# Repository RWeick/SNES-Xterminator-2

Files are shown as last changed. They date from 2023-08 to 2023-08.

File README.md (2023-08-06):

# SNES-Xterminator-2
The Kicad files, rom dump, and GAL JEDEC for the SNES Xterminator 2 cheat device. I have redone the trace layout and added additional pads for SMD components.  
Standard jumper configuration: Pads 2, 4, 6, 8, 10, and 12 are shorted.  

Preliminary analysis suggests the following operation of the GAL, multiplexer, and NAND gates:  

/O19 = A 0xFFE8 and BA 0x0, 0x2, 0x4, 0x6

/SRAM.CS = A 0x2C00 to 0x2FFF and BA 0x0 to 0x1F, which aligns with the fact that the SRAM has 32,768 words.

When Famicom cart is inserted, Famicom CICs 1 and 2 are connected to the system.
When Famicom cart is not inserted, SNES cart CICs 1 and 2 are connected to the system.

The operation of the 18CV8PC is unknown at this time, but I will be analyzing it in operation for reverse engineering.

Main Board PCB Thickness: 1.2 mm  
Cartridge Connector Board PCB Thickness: 1.6 mm  

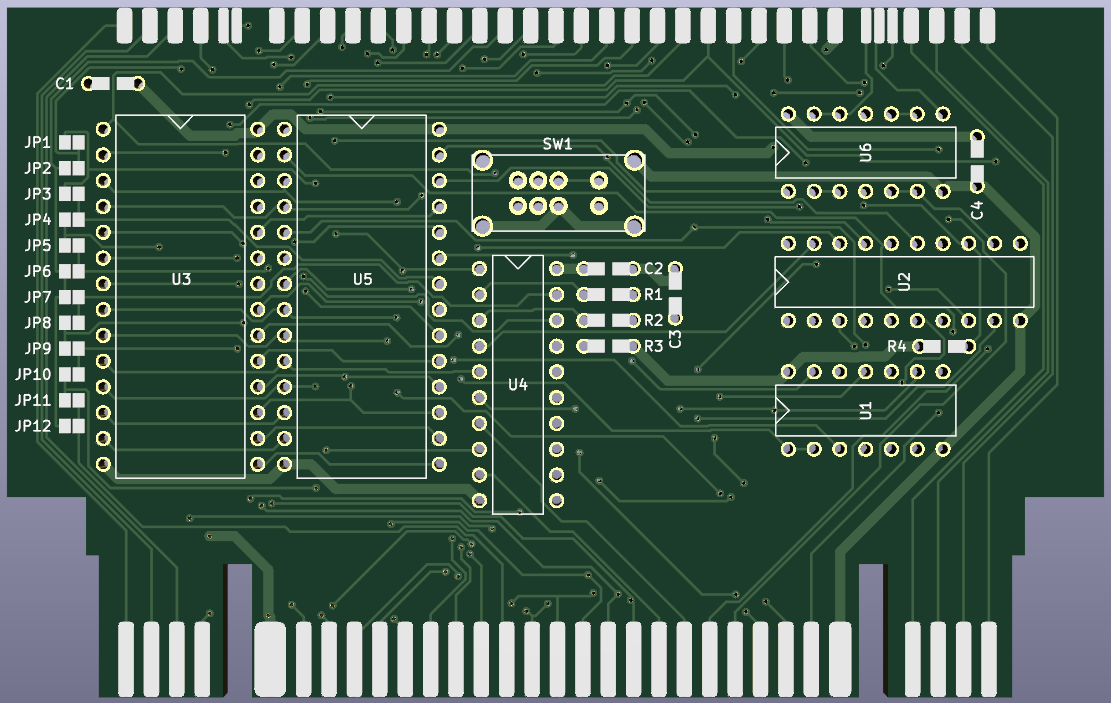
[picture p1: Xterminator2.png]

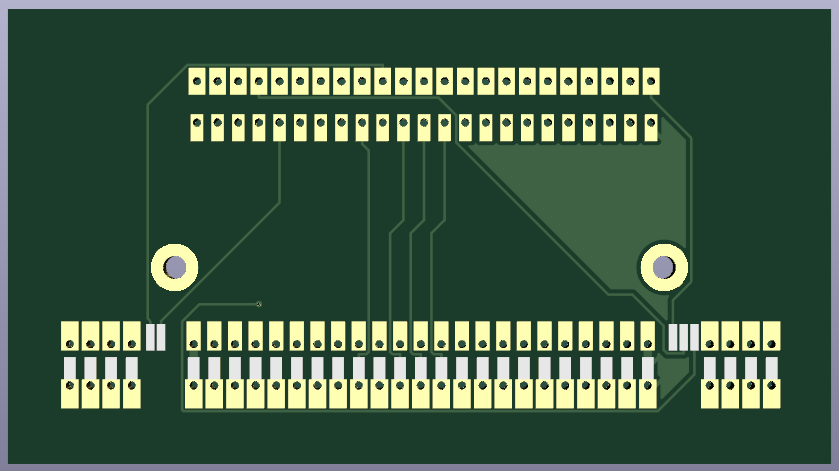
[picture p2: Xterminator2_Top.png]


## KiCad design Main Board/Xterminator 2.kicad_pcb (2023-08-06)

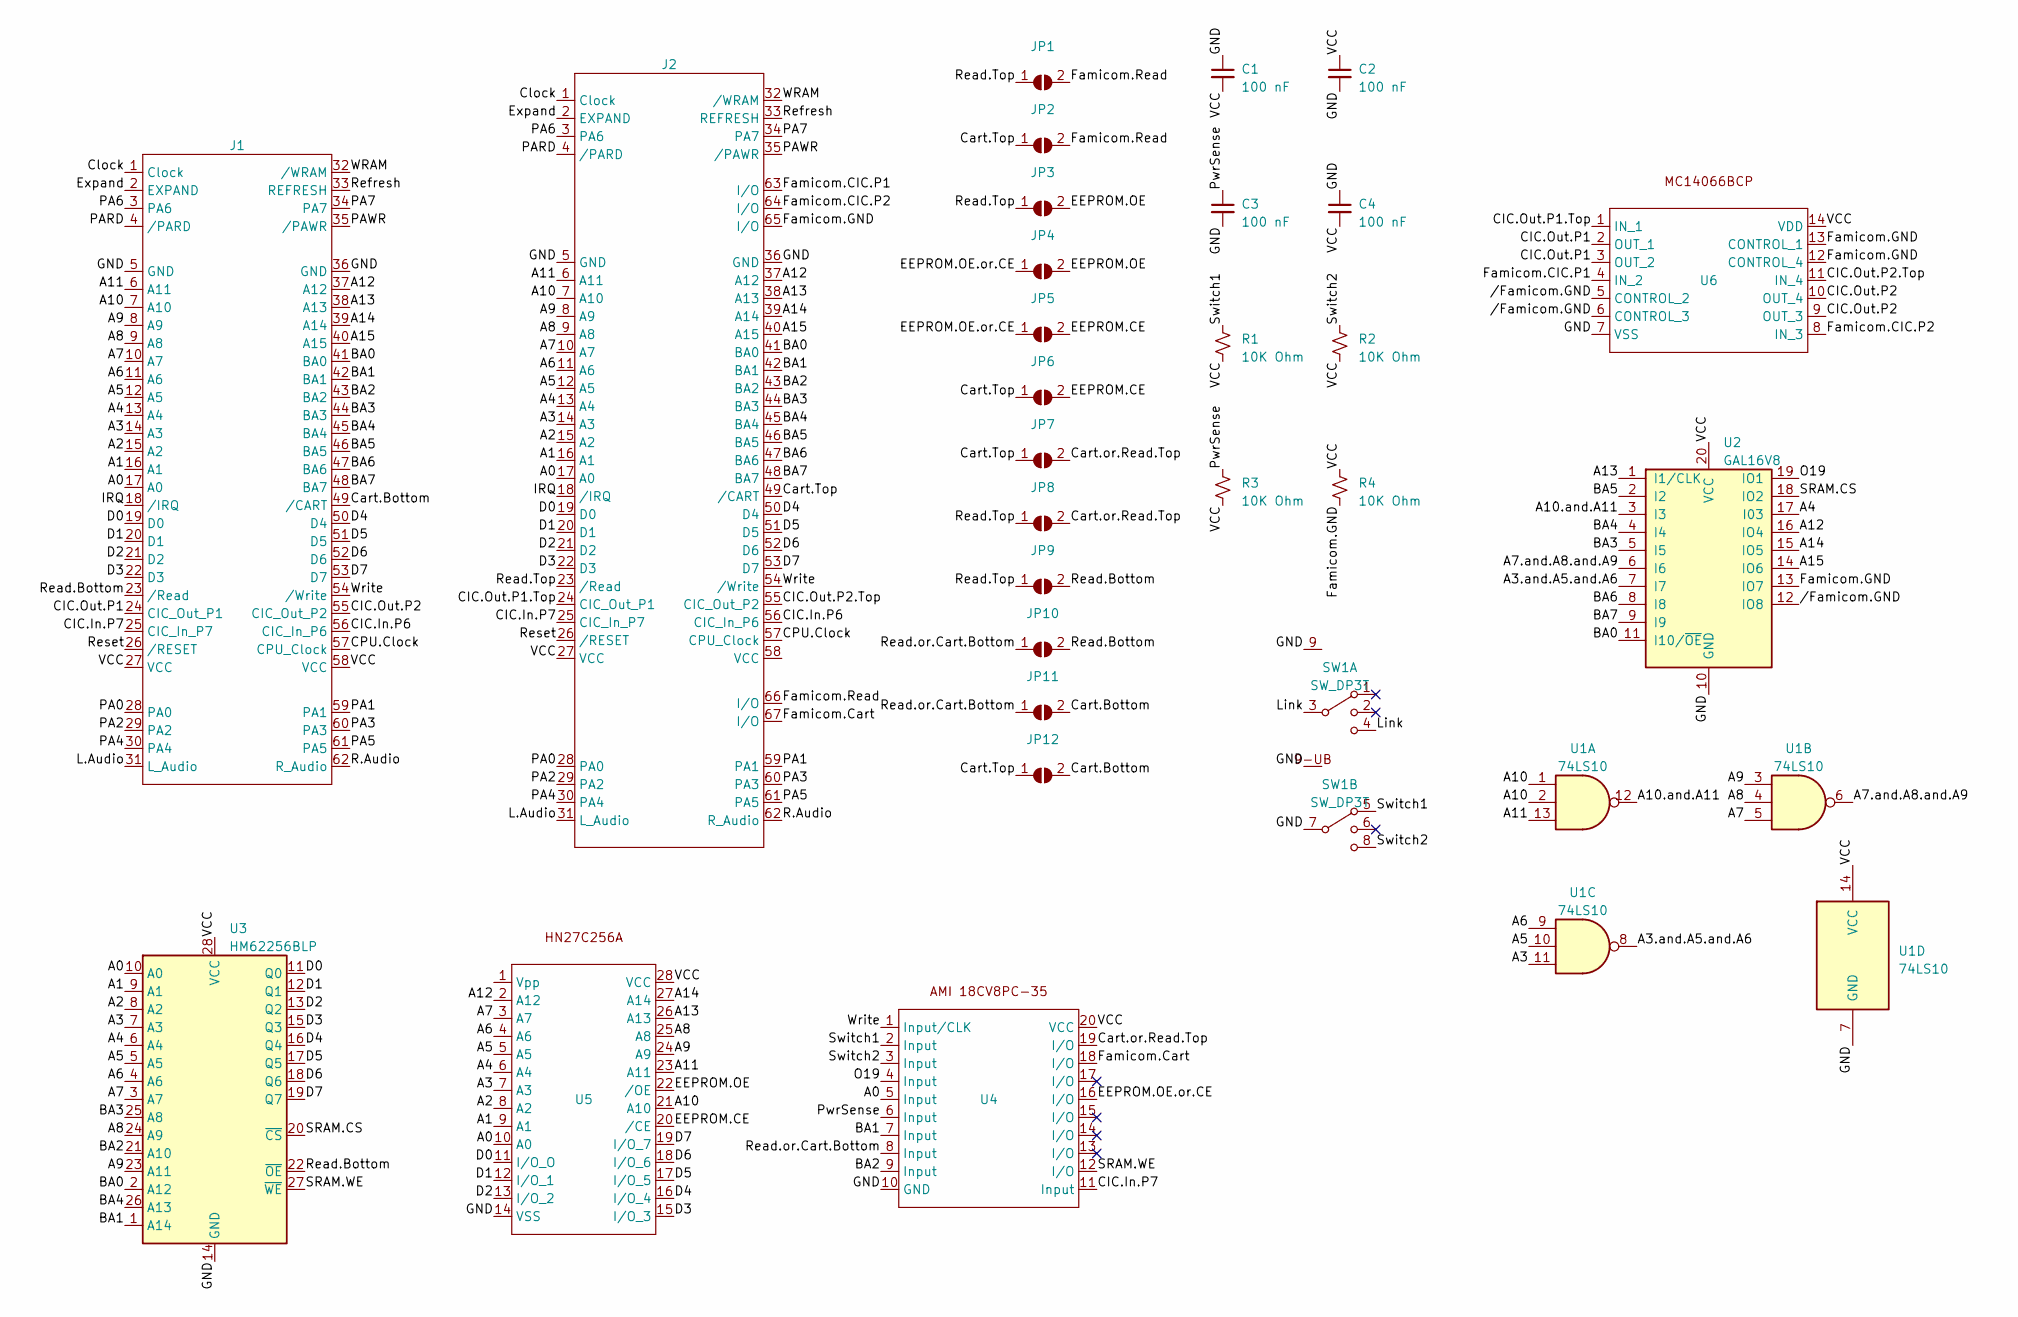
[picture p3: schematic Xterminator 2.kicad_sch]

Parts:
C1, C2, C3, C4: 100 nF; SMD Cap-Res
J1: SNES Edge Connector
J2: Upper Edge Connector
JP1, JP2, JP3, JP4, JP5, JP6, JP7, JP8, JP9, JP10, JP11, JP12: SolderJumper_2_Open; Jumper Pads
R1, R2, R3, R4: 10K Ohm; SMD Cap-Res
SW1: SW_DP3T; Switch
U1: 74LS10
U2: GAL16V8
U3: HM62256BLP; HM62256
U4: 18CVP8C
U5: HN27C256
U6: MC14066BCP

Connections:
/A0: J1.17 (A0), J2.17 (A0), U3.10 (A0), U4.5 (Input), U5.10 (A0)
/A1: J1.16 (A1), J2.16 (A1), U3.9 (A1), U5.9 (A1)
/A2: J1.15 (A2), J2.15 (A2), U3.8 (A2), U5.8 (A2)
/A3: J1.14 (A3), J2.14 (A3), U1.11, U3.7 (A3), U5.7 (A3)
/A3.and.A5.and.A6: U1.8, U2.7 (I7)
/A4: J1.13 (A4), J2.13 (A4), U2.17 (I03), U3.6 (A4), U5.6 (A4)
/A5: J1.12 (A5), J2.12 (A5), U1.10, U3.5 (A5), U5.5 (A5)
/A6: J1.11 (A6), J2.11 (A6), U1.9, U3.4 (A6), U5.4 (A6)
/A7: J1.10 (A7), J2.10 (A7), U1.5, U3.3 (A7), U5.3 (A7)
/A7.and.A8.and.A9: U1.6, U2.6 (I6)
/A8: J1.9 (A8), J2.9 (A8), U1.4, U3.24 (A9), U5.25 (A8)
/A9: J1.8 (A9), J2.8 (A9), U1.3, U3.23 (A11), U5.24 (A9)
/A10: J1.7 (A10), J2.7 (A10), U1.1, U1.2, U5.21 (A10)
/A10.and.A11: U1.12, U2.3 (I3)
/A11: J1.6 (A11), J2.6 (A11), U1.13, U5.23 (A11)
/A12: J1.37 (A12), J2.37 (A12), U2.16 (IO4), U5.2 (A12)
/A13: J1.38 (A13), J2.38 (A13), U2.1 (I1/CLK), U5.26 (A13)
/A14: J1.39 (A14), J2.39 (A14), U2.15 (IO5), U5.27 (A14)
/A15: J1.40 (A15), J2.40 (A15), U2.14 (IO6)
/BA0: J1.41 (BA0), J2.41 (BA0), U2.11 (I10/~OE), U3.2 (A12)
/BA1: J1.42 (BA1), J2.42 (BA1), U3.1 (A14), U4.7 (Input)
/BA2: J1.43 (BA2), J2.43 (BA2), U3.21 (A10), U4.9 (Input)
/BA3: J1.44 (BA3), J2.44 (BA3), U2.5 (I5), U3.25 (A8)
/BA4: J1.45 (BA4), J2.45 (BA4), U2.4 (I4), U3.26 (A13)
/BA5: J1.46 (BA5), J2.46 (BA5), U2.2 (I2)
/BA6: J1.47 (BA6), J2.47 (BA6), U2.8 (I8)
/BA7: J1.48 (BA7), J2.48 (BA7), U2.9 (I9)
/CIC.In.P6: J1.56 (CIC_In_P6), J2.56 (CIC_In_P6)
/CIC.In.P7: J1.25 (CIC_In_P7), J2.25 (CIC_In_P7), U4.11 (Input)
/CIC.Out.P1: J1.24 (CIC_Out_P1), U6.2 (OUT_1), U6.3 (OUT_2)
/CIC.Out.P1.Top: J2.24 (CIC_Out_P1), U6.1 (IN_1)
/CIC.Out.P2: J1.55 (CIC_Out_P2), U6.9 (OUT_3), U6.10 (OUT_4)
/CIC.Out.P2.Top: J2.55 (CIC_Out_P2), U6.11 (IN_4)
/CPU.Clock: J1.57 (CPU_Clock), J2.57 (CPU_Clock)
/Cart.Bottom: J1.49 (/CART), JP11.2 (B), JP12.2 (B)
/Cart.Top: J2.49 (/CART), JP2.1 (A), JP6.1 (A), JP7.1 (A), JP12.1 (A)
/Cart.or.Read.Top: JP7.2 (B), JP8.2 (B), U4.19 (I/O)
/Clock: J1.1 (Clock), J2.1 (Clock)
/D0: J1.19 (D0), J2.19 (D0), U3.11 (Q0), U5.11 (I/O_O)
/D1: J1.20 (D1), J2.20 (D1), U3.12 (Q1), U5.12 (I/O_1)
/D2: J1.21 (D2), J2.21 (D2), U3.13 (Q2), U5.13 (I/O_2)
/D3: J1.22 (D3), J2.22 (D3), U3.15 (Q3), U5.15 (I/O_3)
/D4: J1.50 (D4), J2.50 (D4), U3.16 (Q4), U5.16 (I/O_4)
/D5: J1.51 (D5), J2.51 (D5), U3.17 (Q5), U5.17 (I/O_5)
/D6: J1.52 (D6), J2.52 (D6), U3.18 (Q6), U5.18 (I/O_6)
/D7: J1.53 (D7), J2.53 (D7), U3.19 (Q7), U5.19 (I/O_7)
/EEPROM.CE: JP5.2 (B), JP6.2 (B), U5.20 (/CE)
/EEPROM.OE: JP3.2 (B), JP4.2 (B), U5.22 (/OE)
/EEPROM.OE.or.CE: JP4.1 (A), JP5.1 (A), U4.16 (I/O)
/Expand: J1.2 (EXPAND), J2.2 (EXPAND)
/Famicom.CIC.P1: J2.63 (I/O), U6.4 (IN_2)
/Famicom.CIC.P2: J2.64 (I/O), U6.8 (IN_3)
/Famicom.Cart: J2.67 (I/O), U4.18 (I/O)
/Famicom.GND: J2.65 (I/O), R4.2, U2.13 (IO7), U6.12 (CONTROL_4), U6.13 (CONTROL_1)
/Famicom.Read: J2.66 (I/O), JP1.2 (B), JP2.2 (B)
/GND: C1.1, C2.2, C3.2, C4.1, J1.5 (GND), J1.36 (GND), J2.5 (GND), J2.36 (GND), SW1.7, SW1.9 (Shield), SW1.9-UB (Shield), U1.7 (GND), U2.10 (GND), U3.14 (GND), U4.10 (GND), U5.14 (VSS), U6.7 (VSS)
/IRQ: J1.18 (/IRQ), J2.18 (/IRQ)
/L.Audio: J1.31 (L_Audio), J2.31 (L_Audio)
/Link: SW1.3, SW1.4
/O19: U2.19 (IO1), U4.4 (Input)
/PA0: J1.28 (PA0), J2.28 (PA0)
/PA1: J1.59 (PA1), J2.59 (PA1)
/PA2: J1.29 (PA2), J2.29 (PA2)
/PA3: J1.60 (PA3), J2.60 (PA3)
/PA4: J1.30 (PA4), J2.30 (PA4)
/PA5: J1.61 (PA5), J2.61 (PA5)
/PA6: J1.3 (PA6), J2.3 (PA6)
/PA7: J1.34 (PA7), J2.34 (PA7)
/PARD: J1.4 (/PARD), J2.4 (/PARD)
/PAWR: J1.35 (/PAWR), J2.35 (/PAWR)
/PwrSense: C3.1, R3.1, U4.6 (Input)
/R.Audio: J1.62 (R_Audio), J2.62 (R_Audio)
/Read.Bottom: J1.23 (/Read), JP9.2 (B), JP10.2 (B), U3.22 (~OE)
/Read.Top: J2.23 (/Read), JP1.1 (A), JP3.1 (A), JP8.1 (A), JP9.1 (A)
/Read.or.Cart.Bottom: JP10.1 (A), JP11.1 (A), U4.8 (Input)
/Refresh: J1.33 (REFRESH), J2.33 (REFRESH)
/Reset: J1.26 (/RESET), J2.26 (/RESET)
/SRAM.CS: U2.18 (IO2), U3.20 (~CS)
/SRAM.WE: U3.27 (~WE), U4.12 (I/O)
/Switch1: R1.1, SW1.5, U4.2 (Input)
/Switch2: R2.1, SW1.8, U4.3 (Input)
/VCC: C1.2, C2.1, C4.2, J1.27 (VCC), J1.58 (VCC), J2.27 (VCC), R1.2, R2.2, R3.2, R4.1, U1.14 (VCC), U2.20 (VCC), U3.28 (VCC), U4.20 (VCC), U5.28 (VCC), U6.14 (VDD)
/WRAM: J1.32 (/WRAM), J2.32 (/WRAM)
/Write: J1.54 (/Write), J2.54 (/Write), U4.1 (Input/CLK)
//Famicom.GND: U2.12 (IO8), U6.5 (CONTROL_2), U6.6 (CONTROL_3)

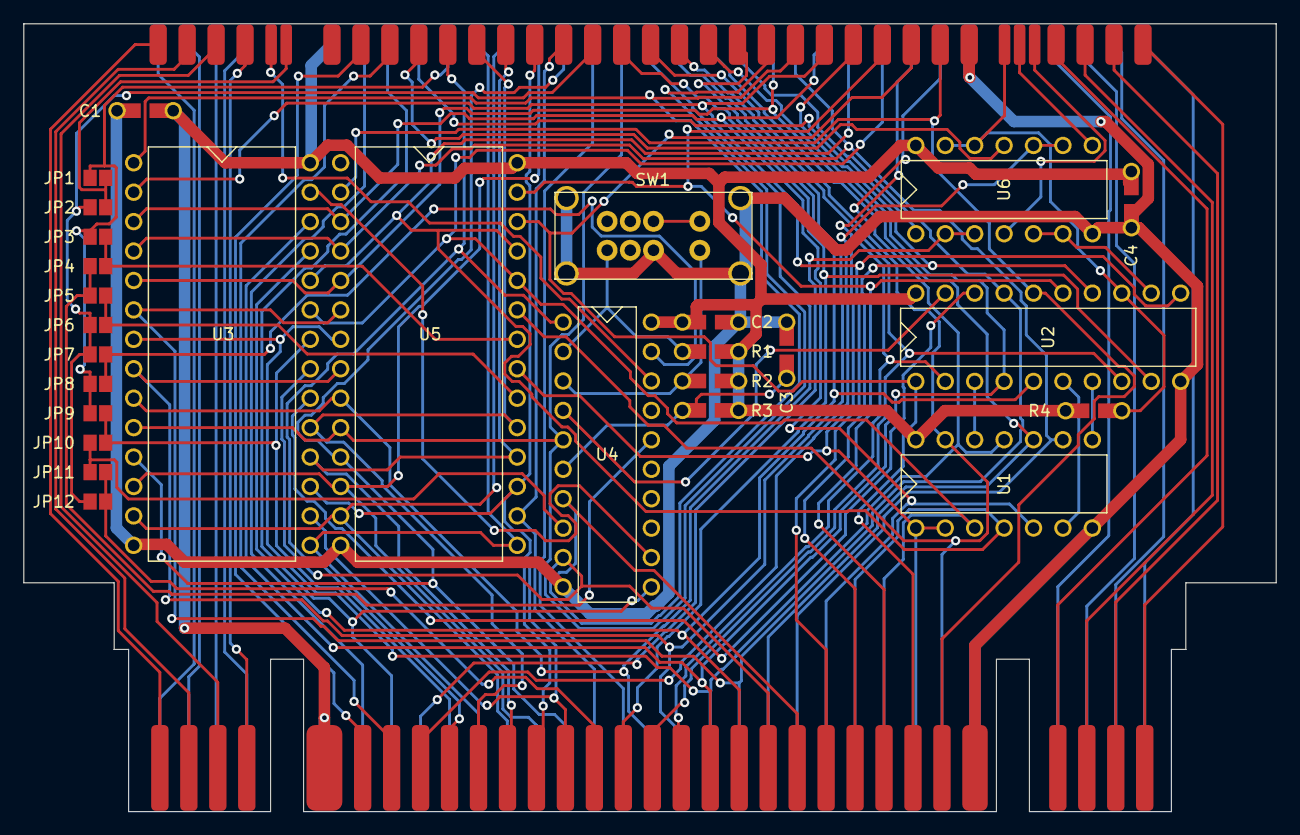
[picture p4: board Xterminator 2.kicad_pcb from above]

Board: 2 copper layers, 108.1 x 68.0 mm, 29 parts (0 on the bottom side), 85 nets.

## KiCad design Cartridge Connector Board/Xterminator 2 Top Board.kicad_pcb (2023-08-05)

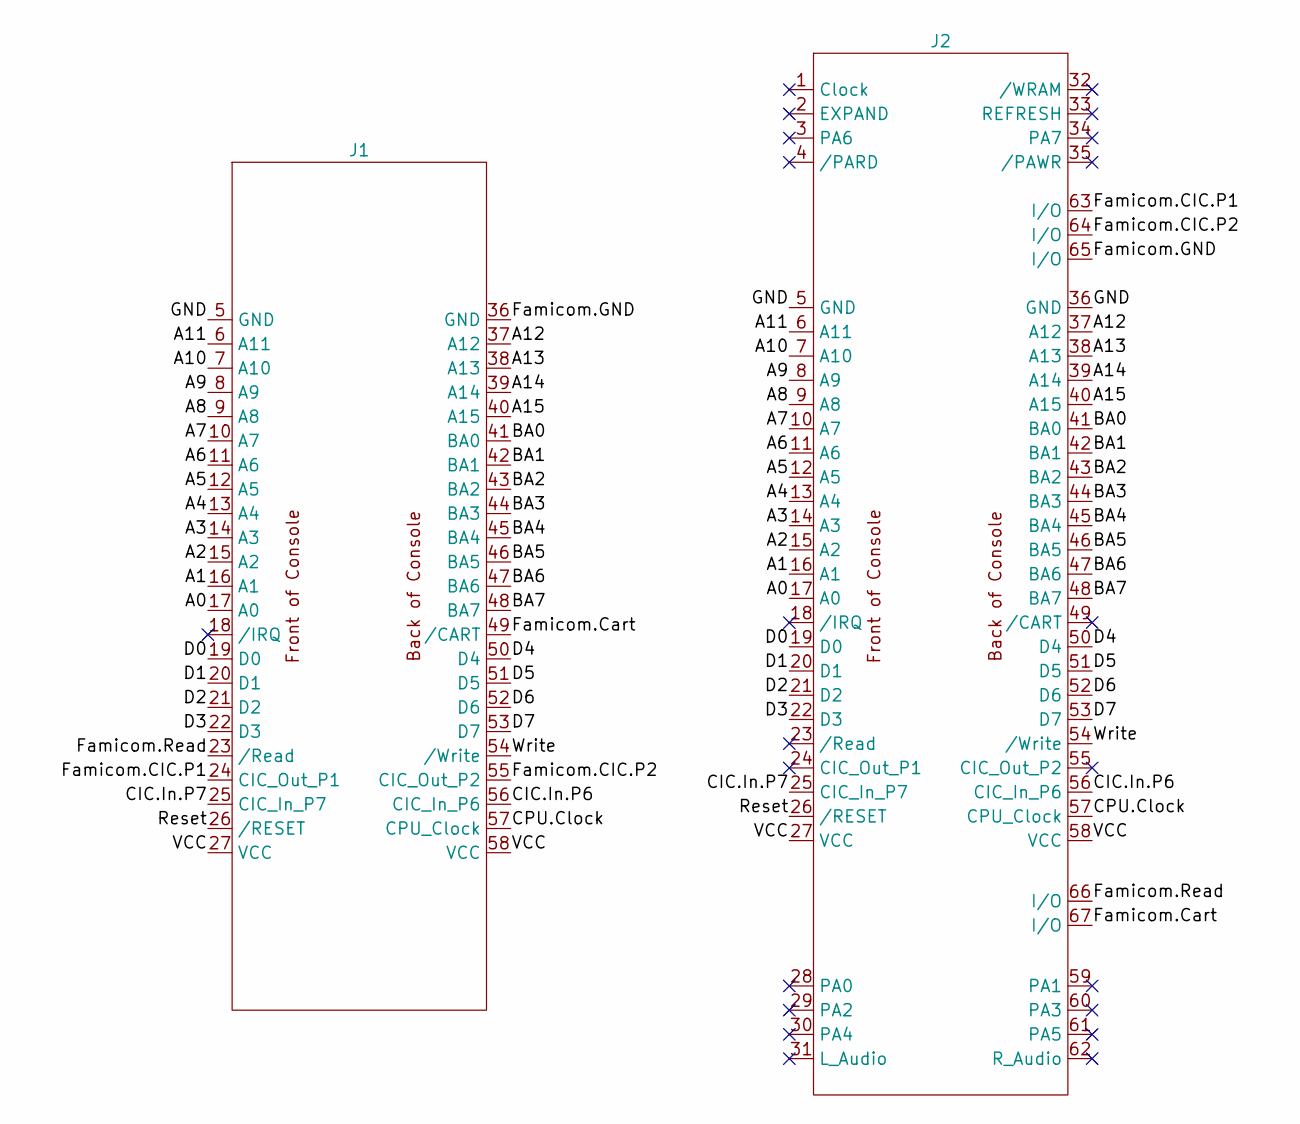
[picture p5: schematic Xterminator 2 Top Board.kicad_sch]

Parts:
J1: Super Famicom Cartridge Slot
J2: SNES Cartridge Slot

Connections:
/A0: J1.17 (A0), J2.17 (A0)
/A1: J1.16 (A1), J2.16 (A1)
/A2: J1.15 (A2), J2.15 (A2)
/A3: J1.14 (A3), J2.14 (A3)
/A4: J1.13 (A4), J2.13 (A4)
/A5: J1.12 (A5), J2.12 (A5)
/A6: J1.11 (A6), J2.11 (A6)
/A7: J1.10 (A7), J2.10 (A7)
/A8: J1.9 (A8), J2.9 (A8)
/A9: J1.8 (A9), J2.8 (A9)
/A10: J1.7 (A10), J2.7 (A10)
/A11: J1.6 (A11), J2.6 (A11)
/A12: J1.37 (A12), J2.37 (A12)
/A13: J1.38 (A13), J2.38 (A13)
/A14: J1.39 (A14), J2.39 (A14)
/A15: J1.40 (A15), J2.40 (A15)
/BA0: J1.41 (BA0), J2.41 (BA0)
/BA1: J1.42 (BA1), J2.42 (BA1)
/BA2: J1.43 (BA2), J2.43 (BA2)
/BA3: J1.44 (BA3), J2.44 (BA3)
/BA4: J1.45 (BA4), J2.45 (BA4)
/BA5: J1.46 (BA5), J2.46 (BA5)
/BA6: J1.47 (BA6), J2.47 (BA6)
/BA7: J1.48 (BA7), J2.48 (BA7)
/CIC.In.P6: J1.56 (CIC_In_P6), J2.56 (CIC_In_P6)
/CIC.In.P7: J1.25 (CIC_In_P7), J2.25 (CIC_In_P7)
/CPU.Clock: J1.57 (CPU_Clock), J2.57 (CPU_Clock)
/D0: J1.19 (D0), J2.19 (D0)
/D1: J1.20 (D1), J2.20 (D1)
/D2: J1.21 (D2), J2.21 (D2)
/D3: J1.22 (D3), J2.22 (D3)
/D4: J1.50 (D4), J2.50 (D4)
/D5: J1.51 (D5), J2.51 (D5)
/D6: J1.52 (D6), J2.52 (D6)
/D7: J1.53 (D7), J2.53 (D7)
/Famicom.CIC.P1: J1.24 (CIC_Out_P1), J2.63 (I/O)
/Famicom.CIC.P2: J1.55 (CIC_Out_P2), J2.64 (I/O)
/Famicom.Cart: J1.49 (/CART), J2.67 (I/O)
/Famicom.GND: J1.36 (GND), J2.65 (I/O)
/Famicom.Read: J1.23 (/Read), J2.66 (I/O)
/GND: J1.5 (GND), J2.5 (GND), J2.36 (GND)
/Reset: J1.26 (/RESET), J2.26 (/RESET)
/VCC: J1.27 (VCC), J1.58 (VCC), J2.27 (VCC), J2.58 (VCC)
/Write: J1.54 (/Write), J2.54 (/Write)

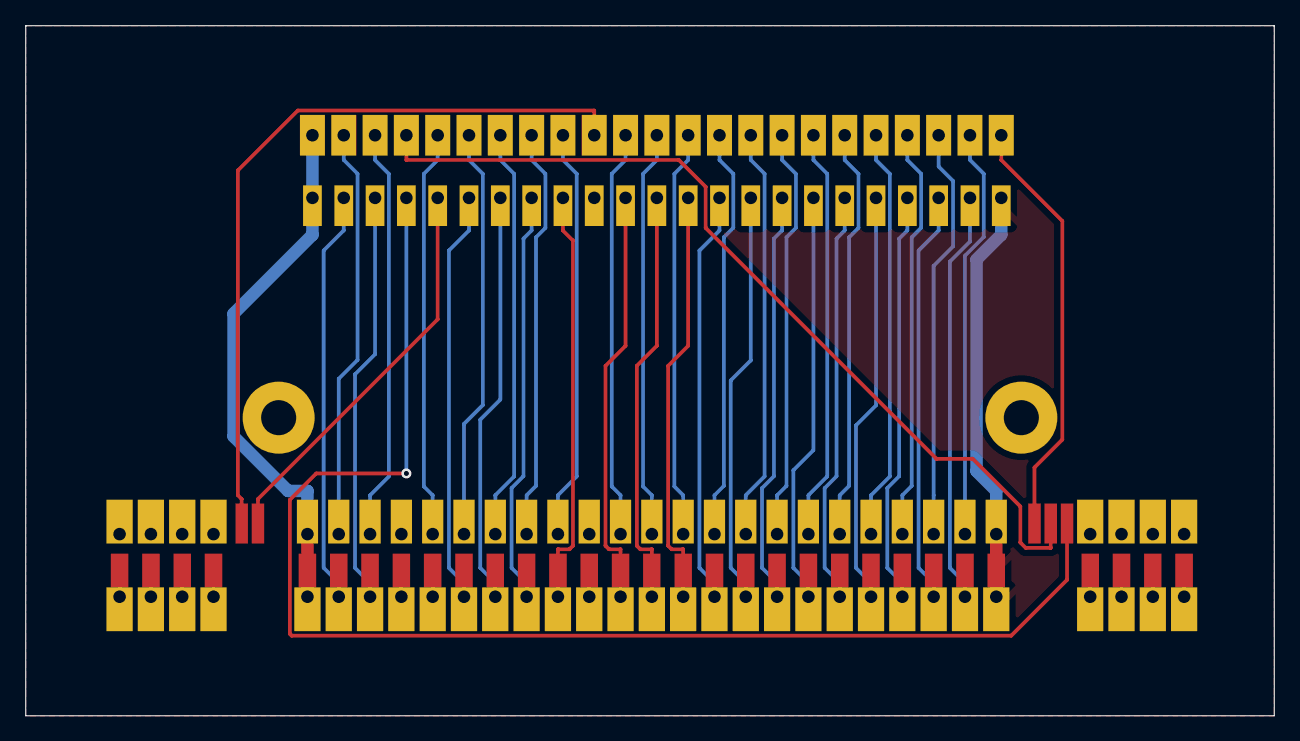
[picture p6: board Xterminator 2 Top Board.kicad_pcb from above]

Board: 2 copper layers, 99.7 x 55.1 mm, 4 parts (0 on the bottom side), 44 nets.

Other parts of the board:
Hole1, Hole2: Screw Hole
